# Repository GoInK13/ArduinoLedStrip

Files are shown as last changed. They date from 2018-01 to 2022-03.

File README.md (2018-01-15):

# ArduinoLedStrip
Arduino PCB to control LED strip RGB, addressable or not, with 1 IR remote, 1 pot and 2 push buttons.

**Kicad information**
This project is made using KiCad Version: 4.0.7-e2-6376~58~ubuntu14.04.1.

**Arduino information**
You need the library "RobotIRremote" in your libraries folder. I also modified "TDK2" to "12" in my arduino-1.6.9/libraries/RobotIRremote/src/IRremoteTools.cpp file.

**Component list**
The Arduino used is an ATmega328P Nano V3.
The DC 12V connector is a 5.5mm×2.1mm DC Power Supply Female Jack Socket.
The 6 transistors used are IRFZ44N Transistor N-Channel.
The polarized power capacitor is a 10µF, with a diameter egal to 8.0mm, and a pitch of 3.5mm.
SW1 and SW2 are Push Button DIP P4.
The potentiometer is a PTV09A from Bourns.
The IR receiver is a TSOP4838.
All pin header used have a pitch of 2.54mm.
All resistors are 0603 handsoldering (1kΩ).
Wemos : D1 mini

**Thanks**
Thanks to jerome-labidurie on GitHub for his d1_mini library. (Wemos)
https://github.com/jerome-labidurie/d1_mini_kicad.git

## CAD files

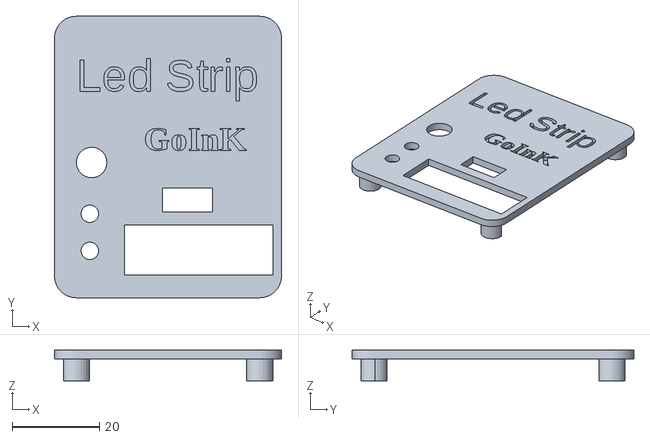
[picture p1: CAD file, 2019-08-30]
FreeCad/top.stl
52.0 x 64.5 x 7.00

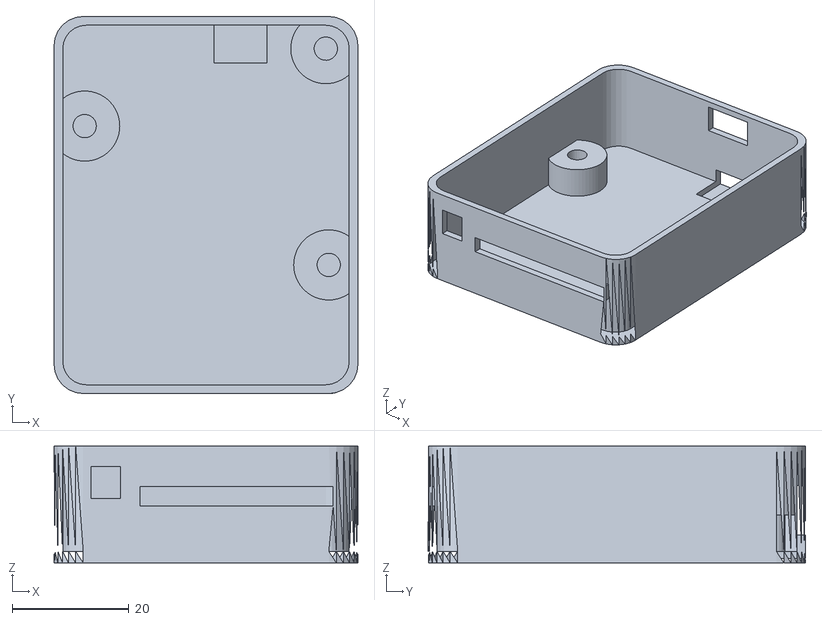
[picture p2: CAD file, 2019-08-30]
FreeCad/bot.stl
52.0 x 64.5 x 20.0

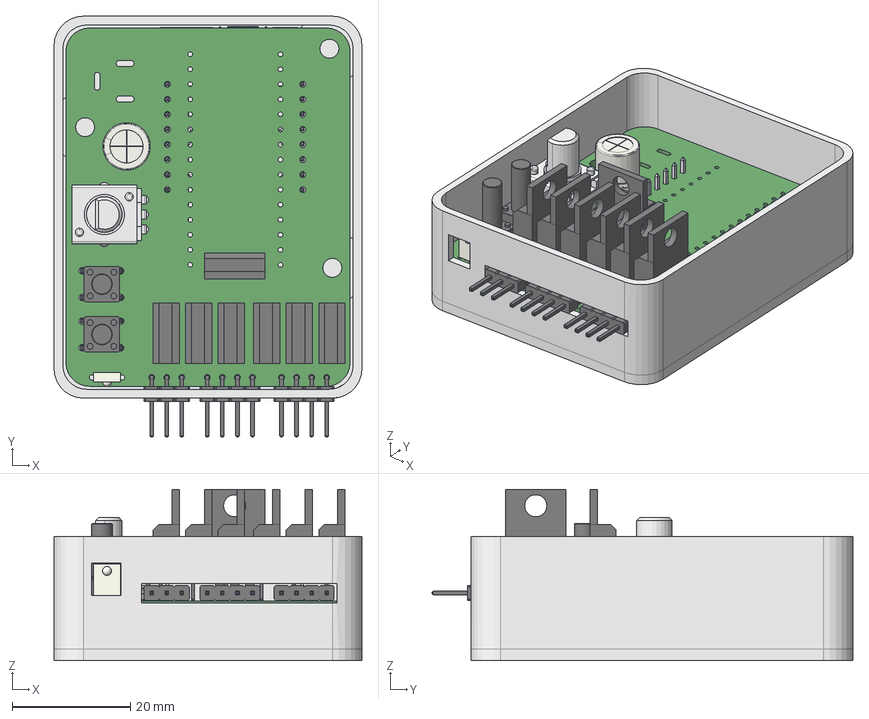
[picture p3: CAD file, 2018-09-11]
FreeCad/ArduinoLedStrip.fcstd
52.0 x 71.0 x 28.9 mm
Bottom2

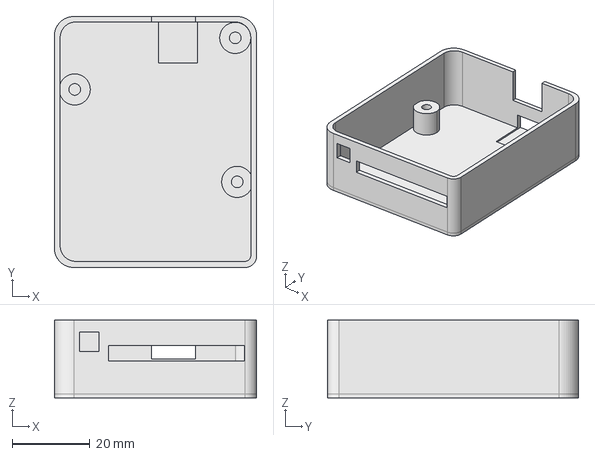
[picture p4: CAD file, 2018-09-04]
FreeCad/Case_Bot.step
52.0 x 64.5 x 20.0 mm

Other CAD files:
FreeCad/Case_top.step

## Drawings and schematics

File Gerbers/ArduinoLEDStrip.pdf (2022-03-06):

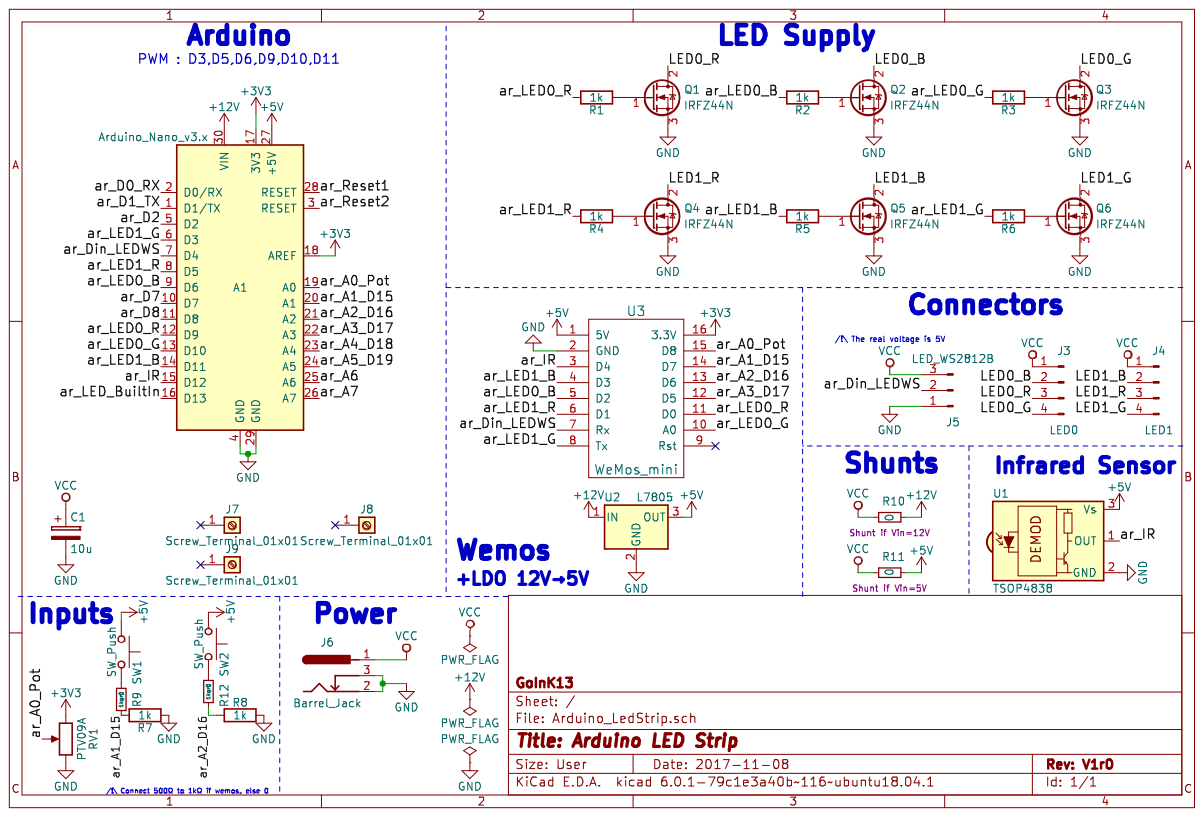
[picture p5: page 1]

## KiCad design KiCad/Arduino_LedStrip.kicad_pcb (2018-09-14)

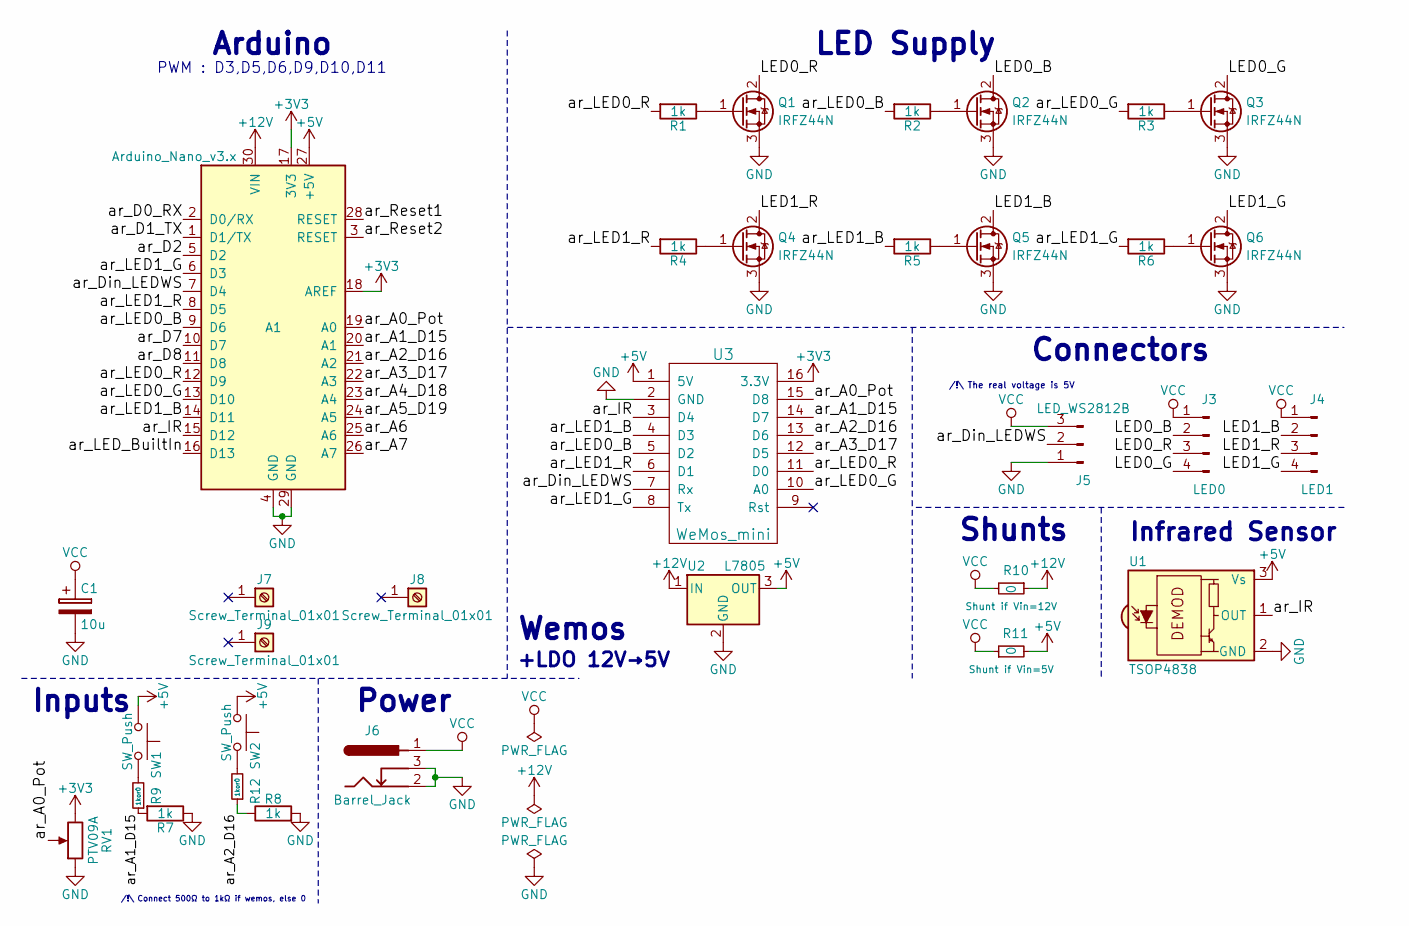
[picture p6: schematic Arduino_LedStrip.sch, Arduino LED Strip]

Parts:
A1: Arduino_Nano_v3.x; Arduino_Nano
C1: 10u; CP_Radial_D8.0mm_P3.50mm
J3: LED0; Pin_Header_Angled_1x04_Pitch2.54mm
J4: LED1; Pin_Header_Angled_1x04_Pitch2.54mm
J5: LED_WS2812B; Pin_Header_Angled_1x03_Pitch2.54mm
J6: Barrel_Jack; BARREL_JACK
J7, J8, J9: Screw_Terminal_01x01; MountingHole_3.2mm_M3
Q1, Q2, Q3, Q4, Q5, Q6: IRFZ44N; TO-220-3_Vertical
R1, R2, R3, R4, R5, R6, R7, R8: 1k; R_0603_HandSoldering
R9, R12: 1kor0; R_0603_HandSoldering
R10, R11: 0; R_Shunt
RV1: PTV09A; Potentiometer_Bourns_PTV09A-1_Horizontal
SW1, SW2: SW_Push; SW_PUSH_6mm_h13mm
U1: TSOP4838; IRReceiver_Vishay_MOLD-3pin
U2: L7805; TO-220-3_Vertical
U3: WeMos_mini; D1_mini_board

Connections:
+3V3: A1.17 (3V3), A1.18 (AREF), RV1.3, U3.16 (3.3V)
+5V: A1.27 (+5V), R11.2, SW1.1, SW2.1, U1.3 (Vs), U2.3 (OUT), U3.1 (5V)
+12V: A1.30 (VIN), R10.1, U2.1 (IN)
/LED0_B: J3.2, Q2.2 (D)
/LED0_G: J3.4, Q3.2 (D)
/LED0_R: J3.3, Q1.2 (D)
/LED1_B: J4.2, Q5.2 (D)
/LED1_G: J4.4, Q6.2 (D)
/LED1_R: J4.3, Q4.2 (D)
/ar_A0_Pot: A1.19 (A0), RV1.2, U3.15 (D8)
/ar_A1_D15: A1.20 (A1), R7.2, R9.1, U3.14 (D7)
/ar_A2_D16: A1.21 (A2), R8.1, R12.1, U3.13 (D6)
/ar_A3_D17: A1.22 (A3), U3.12 (D5)
/ar_A4_D18: A1.23 (A4)
/ar_A5_D19: A1.24 (A5)
/ar_A6: A1.25 (A6)
/ar_A7: A1.26 (A7)
/ar_D0_RX: A1.2 (D0/RX)
/ar_D1_TX: A1.1 (D1/TX)
/ar_D2: A1.5 (D2)
/ar_D7: A1.10 (D7)
/ar_D8: A1.11 (D8)
/ar_Din_LEDWS: A1.7 (D4), J5.2, U3.7 (Rx)
/ar_IR: A1.15 (D12), U1.1 (OUT), U3.3 (D4)
/ar_LED0_B: A1.9 (D6), R2.2, U3.5 (D2)
/ar_LED0_G: A1.13 (D10), R3.2, U3.10 (A0)
/ar_LED0_R: A1.12 (D9), R1.2, U3.11 (D0)
/ar_LED1_B: A1.14 (D11), R5.2, U3.4 (D3)
/ar_LED1_G: A1.6 (D3), R6.2, U3.8 (Tx)
/ar_LED1_R: A1.8 (D5), R4.2, U3.6 (D1)
/ar_LED_BuiltIn: A1.16 (D13)
/ar_Reset1: A1.28 (RESET)
/ar_Reset2: A1.3 (RESET)
GND: A1.4 (GND), A1.29 (GND), C1.2, J5.1, J6.2, J6.3, Q1.3 (S), Q2.3 (S), Q3.3 (S), Q4.3 (S), Q5.3 (S), Q6.3 (S), R7.1, R8.2, RV1.1, U1.2 (GND), U2.2 (GND), U3.2 (GND)
unnamed: Q1.1 (G), R1.1
unnamed: Q2.1 (G), R2.1
unnamed: Q3.1 (G), R3.1
unnamed: Q4.1 (G), R4.1
unnamed: Q5.1 (G), R5.1
unnamed: Q6.1 (G), R6.1
unnamed: R9.2, SW1.2
unnamed: R12.2, SW2.2
VCC: C1.1, J3.1, J4.1, J5.3, J6.1, R10.2, R11.1

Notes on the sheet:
PWM : D3,D5,D6,D9,D10,D11
Power
Inputs
Arduino
LED Supply
Connectors
Infrared Sensor
/!\ The real voltage is 5V
Wemos
+LDO 12V→5V
Shunts
/!\ Connect 500Ω to 1kΩ if wemos, else 0

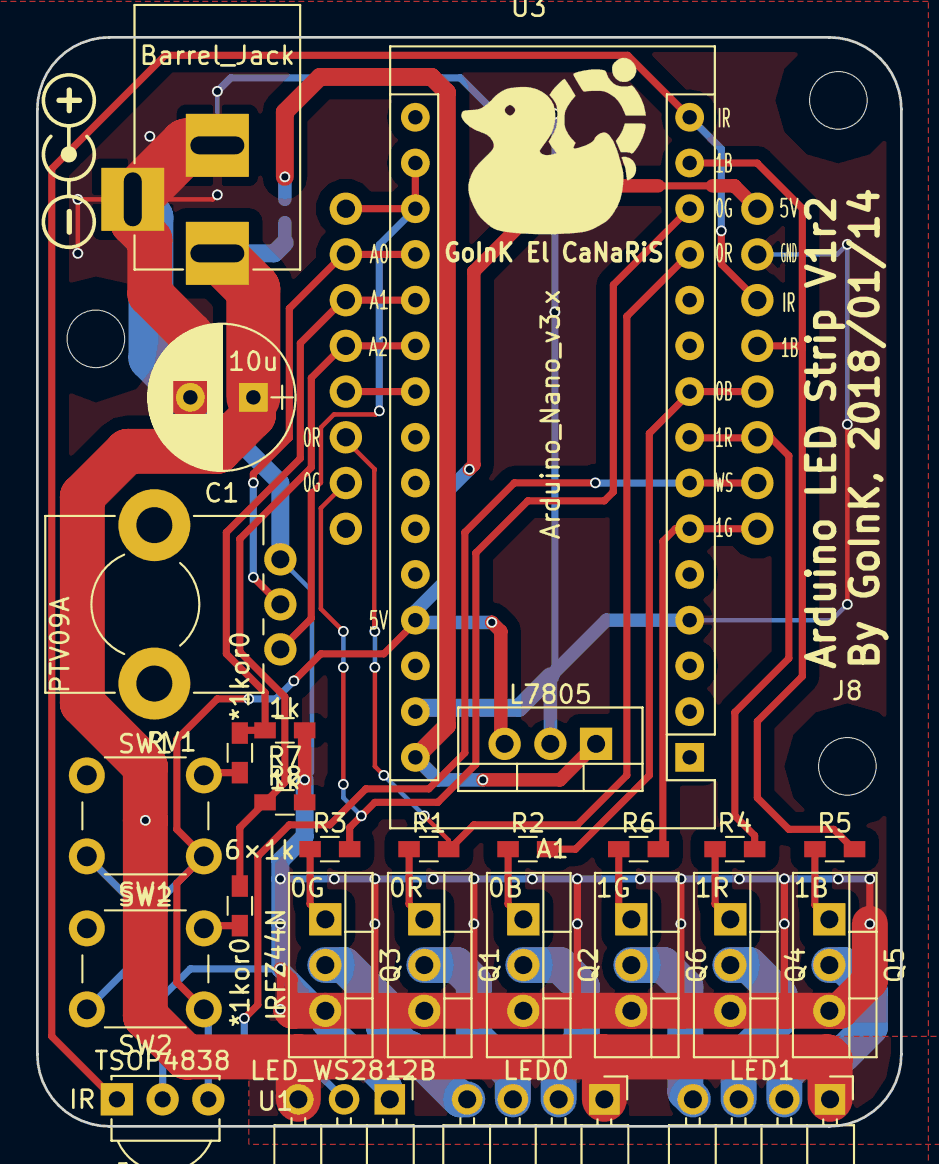
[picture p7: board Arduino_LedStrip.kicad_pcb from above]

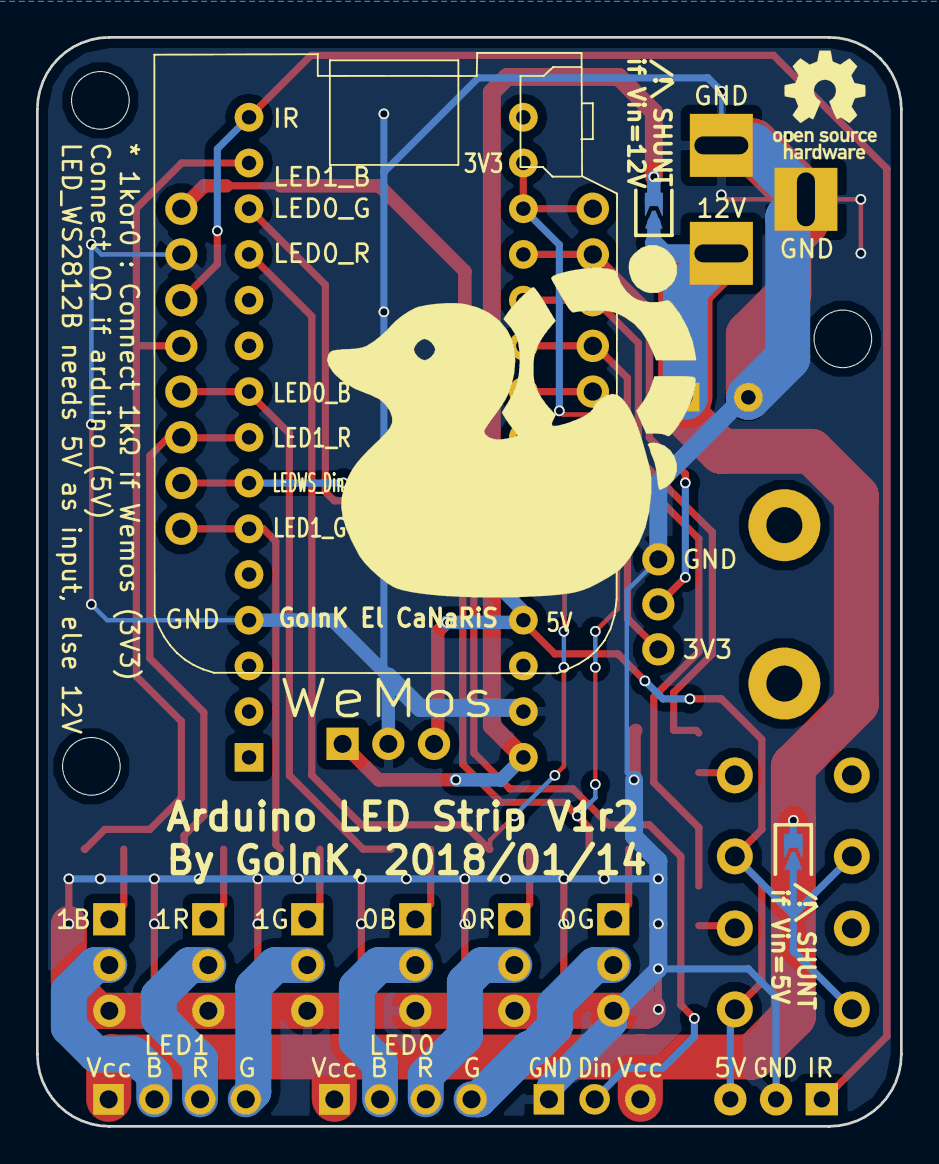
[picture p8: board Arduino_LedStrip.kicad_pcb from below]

Board: 2 copper layers, 48.0 x 60.5 mm, 33 parts (2 on the bottom side), 31 nets.

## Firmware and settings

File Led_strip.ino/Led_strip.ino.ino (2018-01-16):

/*
   20DF9E61 = Ratio
   20DF8976 = AD
*/

#include <IRremote.h>
#include "define.h"
#include <EEPROM.h>

//Uncomment the next to enable USB debug
//#define DBG
//Next is removed, bevause LED1_R doesn't work with IR_Receiver…
//#define IR_RECV

//Const
//const int pwmStepSize = 50;		//Choose number of step for PWM brightness.
//int pwmStep[pwmStepSize]; //Old value : = {0,1,2,5,8,11,15,20,26,33,41,51,64,80,100,125,160,200,255};
const int pwmStepSize = 37;    //Number of step for PWM brightness.
int pwmStep[] = {0, 1, 2, 3, 4, 5, 6, 7, 8, 9, 11, 13, 15, 17, 19, 22, 25, 28, 32, 36, 40, 45, 51, 57, 64, 72, 81, 91, 102, 114, 128, 143, 161, 180, 202, 226, 255};

//Current settings
int pwmIndexR = 0, pwmIndexG = 0, pwmIndexB = 0;		//Current PWM settings
int cntTransition = 0;	//Count transition for fade and jump.
int stateSet = 0;	//Number of settings currently setting. 0 : settings currently not enabled
int mode = 0; //0:color fixed. 1:RGB fading. 2:RGB jumping. 3:Night = Slowly turn OFF, then ON after Xhours

//Saved in EEPROM. To update eeprom after values have changed, you need to click the setting button until going to set 0.
int set0_R, set0_G, set0_B;	//Mode 0 : fix color
int set1_speed;	//Speed transition in ms. Fade
int set2_speed;	//Speed transition in ms. Jump
//Color before night and after. delayNight is in 30min + 5h. ie:2blinks=6h
int set3_colorBeforeR, set3_colorBeforeG, set3_colorBeforeB, set3_colorAfterR, set3_colorAfterG, set3_colorAfterB, set3_delayNight;

unsigned long mode3_nightStarting;	//millis() start when entering in this mode

unsigned int oldPot=0;	//Save the old value of POT, before update it

//Next two lines are used for IR receiver. I added a "2" because I had some compilation troubble with the lib IRremote.h.
//I also changed "TKD2" in IRremoteTools.cpp with "12"

#ifdef IR_RECV
IRrecv irrecv2(IR_RECV_PIN);
decode_results results2;
#endif

void setup()
{
  //Define all output
  //Internal LED used to see good IR reception
  pinMode(LED_BUILTIN, OUTPUT);
  pinMode(LED0_R, OUTPUT);
  pinMode(LED0_G, OUTPUT);
  pinMode(LED0_B, OUTPUT);
  pinMode(LED1_R, OUTPUT);
  pinMode(LED1_G, OUTPUT);
  pinMode(LED1_B, OUTPUT);
  pinMode(LEDWS_Din, OUTPUT);
  //Set all LED to LOW
  digitalWrite(LED_BUILTIN, HIGH);
  digitalWrite(LED0_R, LOW);
  digitalWrite(LED0_G, LOW);
  digitalWrite(LED0_B, LOW);
  digitalWrite(LED1_R, LOW);
  digitalWrite(LED1_G, LOW);
  digitalWrite(LED1_B, LOW);
  digitalWrite(LEDWS_Din, LOW);
  //Inputs : Push button and analog
  pinMode(BUTTON0, INPUT);
  pinMode(BUTTON1, INPUT);
  //Pot doesn't need to be initialized, because it's an analog
  //Save number of values in pwmStep

  //Init values from EEPROM
  if (EEPROM.read(101) != 1 || (digitalRead(BUT_MODE) == 1 && digitalRead(BUT_SET) == 1)) {	//Two buttons pressed on boot = RESET settings
    mode = 0;
    set0_R = pwmStepSize - 1;
    set0_G = pwmStepSize - 1;
    set0_B = pwmStepSize - 1;
    set1_speed = 100;
    set2_speed = 100;
    set3_colorBeforeR = pwmStepSize - 1;
    set3_colorBeforeG = pwmStepSize - 1;
    set3_colorBeforeB = pwmStepSize - 1;
    set3_colorAfterR = pwmStepSize - 1;
    set3_colorAfterG = pwmStepSize - 1;
    set3_colorAfterB = pwmStepSize - 1;
    set3_delayNight = 4;
    EepromUpdateAll();	//Save all
  } else {
    mode = EEPROM.read(100);
    //Mode 0
    set0_R = EEPROM.read(1);
    set0_G = EEPROM.read(2);
    set0_B = EEPROM.read(3);
    //Mode 1
    set1_speed = EEPROM.read(10);
    //Mode 2
    set2_speed = EEPROM.read(20);
    //Mode 3
    set3_colorBeforeR = EEPROM.read(30);
    set3_colorBeforeG = EEPROM.read(31);
    set3_colorBeforeB = EEPROM.read(32);
    set3_colorAfterR = EEPROM.read(33);
    set3_colorAfterG = EEPROM.read(34);
    set3_colorAfterB = EEPROM.read(35);
    set3_delayNight = EEPROM.read(36);
  }
  /*
    //Update pwmStep using pwm exponential led fading method. Thanks to diarmuidie : https://diarmuid.ie/blog/pwm-exponential-led-fading-on-arduino-or-other-platforms/
    float R = ((pwmStepSize-1) * log10(2))/(log10(255));
    for (int interval = 0; interval < pwmStepSize; interval++) {
  	// Calculate the required PWM value for this interval step
  	pwmStep[interval]=pow(2, (interval / R)) - 1;
    }
  */

#ifdef IR_RECV
  irrecv2.enableIRIn(); // Start the receiver
#endif
#ifdef DBG
  Serial.begin(115200);
  Serial.print("Enabled IRin.! pwmStep=");
  Serial.println(pwmStepSize);
#endif
  delay(100);		//Slow booting delay to see the BUILTIN LED blink
  digitalWrite(LED_BUILTIN, LOW);
}

void loop() {

#ifdef IR_RECV
  if (irrecv2.decode(&results2)) {	//IR decoded
    digitalWrite(LED_BUILTIN, HIGH);
#ifdef DBG
    Serial.print(pwmIndexR);
    Serial.print(". VAL=");
    Serial.print(results2.value, HEX);
#endif
    if (results2.value == IR_LG_BLUE) {	//Increase power of blue
      if (pwmIndexB < pwmStepSize - 1)
        pwmIndexB++;
    } else if (results2.value == IR_LG_RED) {
      if (pwmIndexR < pwmStepSize - 1)
        pwmIndexR++;
    } else if (results2.value == IR_LG_GREEN) {
      if (pwmIndexG < pwmStepSize - 1)
        pwmIndexG++;
    }
    analogWrite(LED0_R, pwmStep[pwmIndexR]);
    analogWrite(LED0_G, pwmStep[pwmIndexG]);
    analogWrite(LED0_B, pwmStep[pwmIndexB]);
    analogWrite(LED1_R, pwmStep[pwmIndexR]);
    analogWrite(LED1_G, pwmStep[pwmIndexG]);
    analogWrite(LED1_B, pwmStep[pwmIndexB]);
    irrecv2.resume(); // Receive the next value
  }
#endif
  if (digitalRead(BUT_MODE) == 1) {	//Transition button mode
    while (digitalRead(BUT_MODE) == 1);  //Wait releasing button
    Blink(mode + 1);
    stateSet = 0;
    pwmIndexR = 0;
    pwmIndexG = 0;
    pwmIndexB = 0;
    cntTransition = 0;
    if (mode == 3) {	//Mode night
      mode3_nightStarting = millis();
    }
    if (mode == 0) {
      EepromUpdateAll();  //Save all
    }
  }
  if (digitalRead(BUT_SET) == 1) {	//Transition button mode
    ShowSettings(stateSet + 1);
    oldPot=analogRead(POT);
    while (digitalRead(BUT_SET) == 1);	//Wait releasing button
  }
  if (stateSet != 0) {
    SetSettings();
  } else {
    UpdateLED(mode);
  }
  LightLED();

#ifdef DBG
  Serial.println();
  Serial.print("Mode=");
  Serial.print(mode);
  Serial.print(", set=");
  Serial.print(stateSet);
  Serial.print(",R=");
  Serial.print(pwmIndexR);
  Serial.print(",G=");
  Serial.print(pwmIndexG);
  Serial.print(",B=");
  Serial.print(pwmIndexB);
  Serial.print(",POT=");
  Serial.print(analogRead(POT));
  delay(100);
#endif
}

//-----------FUNCTIONS-----------

/*
	UpdateLED from mode
*/
void UpdateLED(int _mode) {
  if (_mode == 0) {		//Fix
    pwmIndexR = set0_R;
    pwmIndexG = set0_G;
    pwmIndexB = set0_B;
  } else if (_mode == 1) {
    cntTransition = cntTransition >= 6 * pwmStepSize ? 0 : cntTransition + 1;
    /*
      0    0    0    OFF        ---
      0    0    1    Blue       470
      0    1    1    Turquoise  510     Représentant les couleurs selon leur longueur
      0    1    0    Green      540     d'onde, de la plus faible à la plus grande
      1    1    0    Yellow     575
      1    0    0    Red        650
      1    0    1    Pink       400
      1    1    1    White      ---
    */
    if (cntTransition <= 1 * pwmStepSize) {
      pwmIndexR = pwmIndexR == 0 ? 0 : pwmIndexR - 1;
    } else if (cntTransition <= 2 * pwmStepSize) {
      pwmIndexG = pwmIndexG >= pwmStepSize - 1 ? pwmStepSize - 1 : pwmIndexG + 1;
    } else if (cntTransition <= 3 * pwmStepSize) {
      pwmIndexB = pwmIndexB == 0 ? 0 : pwmIndexB - 1;
    } else if (cntTransition <= 4 * pwmStepSize) {
      pwmIndexR = pwmIndexR >= pwmStepSize - 1 ? pwmStepSize - 1 : pwmIndexR + 1;
    } else if (cntTransition <= 5 * pwmStepSize) {
      pwmIndexG = pwmIndexG == 0 ? 0 : pwmIndexG - 1;
    } else if (cntTransition <= 6 * pwmStepSize) {
      pwmIndexB = pwmIndexB >= pwmStepSize - 1 ? pwmStepSize - 1 : pwmIndexB + 1;
    }
    DelayInter(set1_speed);
  } else if (_mode == 2) { //Jump
    cntTransition = cntTransition >= 6 ? 1 : cntTransition + 1;
    /*
      R    G    B
      0    0    1    Blue       470		001	1
      0    1    1    Turquoise  510     010	2
      0    1    0    Green      540     011	3
      1    1    0    Yellow     575		100	4
      1    0    0    Red        650		101	5
      1    0    1    Pink       400		110	6
    */
    if (cntTransition == 1 || cntTransition == 2 || cntTransition == 6) {
      pwmIndexB = pwmStepSize-1;
    } else {
      pwmIndexB = 0;
    }
    if (cntTransition == 2 || cntTransition == 3 || cntTransition == 4) {
      pwmIndexG = pwmStepSize-1;
    } else {
      pwmIndexG = 0;
    }
    if (cntTransition == 4 || cntTransition == 5 || cntTransition == 6) {
      pwmIndexR = pwmStepSize-1;
    } else {
      pwmIndexR = 0;
    }
    DelayInter(set2_speed);
  } else if (_mode == 3) {	//Night
    if (millis() - mode3_nightStarting < 1800000) { //30 first minutes
      static unsigned long temp_powerNight;
      temp_powerNight = (millis() - mode3_nightStarting) * pwmStepSize / 1800000;
      pwmIndexR = set3_colorBeforeR * (pwmStepSize - temp_powerNight) / pwmStepSize;
      pwmIndexG = set3_colorBeforeG * (pwmStepSize - temp_powerNight) / pwmStepSize;
      pwmIndexB = set3_colorBeforeB * (pwmStepSize - temp_powerNight) / pwmStepSize;
    } else if (millis() - mode3_nightStarting < 21600000 + set3_delayNight * 1800000) { //During night
      pwmIndexR = 0;
      pwmIndexG = 0;
      pwmIndexB = 0;
    } else {
      static unsigned long temp_powerNight;
      temp_powerNight = (millis() - mode3_nightStarting - 0 - set3_delayNight * 30000) * pwmStepSize / 30000;
      temp_powerNight = (millis() - mode3_nightStarting - 21600000 - set3_delayNight * 1800000) * pwmStepSize / 1800000;
      if (temp_powerNight < pwmStepSize) {
        pwmIndexR = set3_colorAfterR * temp_powerNight / pwmStepSize;
        pwmIndexG = set3_colorAfterG * temp_powerNight / pwmStepSize;
        pwmIndexB = set3_colorAfterB * temp_powerNight / pwmStepSize;
      } else {
        pwmIndexR = set3_colorAfterR;
        pwmIndexG = set3_colorAfterG;
        pwmIndexB = set3_colorAfterB;
      }
    }
  }
}

/*
	Light LED using global pwm_index
*/
void LightLED() {
  analogWrite(LED0_R, pwmStep[pwmIndexR]);
  analogWrite(LED0_G, pwmStep[pwmIndexG]);
  analogWrite(LED0_B, pwmStep[pwmIndexB]);
  analogWrite(LED1_R, pwmStep[pwmIndexR]);
  analogWrite(LED1_G, pwmStep[pwmIndexG]);
  analogWrite(LED1_B, pwmStep[pwmIndexB]);
}
/*
	Update variables settings in current mode and settings. Use Analog
*/
void SetSettings() {
  int i;
  static unsigned int localR=0, localG=0, localB=0;
  static unsigned int localTemp = 0;
  if (mode == 0) {
    if (stateSet == 1) {		//All
      if (oldPot/5!=analogRead(POT)/5) {    // /5 : avoid low oscillations
        oldPot=-1;  //Set impossible value to oldPot. Avoid oldPot==analogRead(POT)
        TurnAllLED_Pot(analogRead(POT), &pwmIndexR, &pwmIndexG, &pwmIndexB);
      } else {
        pwmIndexR=set0_R;
        pwmIndexG=set0_G;
        pwmIndexB=set0_B;
      }
      localR=pwmIndexR;
      localG=pwmIndexG;
      localB=pwmIndexB;
    } else if (stateSet == 2) {
      if (oldPot/5!=analogRead(POT)/5) {    // /5 : avoid low oscillations
        oldPot=-1;  //Set impossible value to oldPot. Avoid oldPot==analogRead(POT)
        pwmIndexR = (unsigned long) localR*analogRead(POT)/1023;
        pwmIndexG = (unsigned long) localG*analogRead(POT)/1023;
        pwmIndexB = (unsigned long) localB*analogRead(POT)/1023;
      } else {
        pwmIndexR=localR;
        pwmIndexG=localG;
        pwmIndexB=localB;
      }
    }
  } else if (mode == 1) {
    if (stateSet == 1 || stateSet == 2) {
      cntTransition = cntTransition >= 6 * pwmStepSize ? 0 : cntTransition + 1;
      if (cntTransition <= 1 * pwmStepSize) {
        localR = localR == 0 ? 0 : localR - 1;
      } else if (cntTransition <= 2 * pwmStepSize) {
        localG = localG >= pwmStepSize-1 ? pwmStepSize-1 : localG + 1;
      } else if (cntTransition <= 3 * pwmStepSize) {
        localB = localB == 0 ? 0 : localB - 1;
      } else if (cntTransition <= 4 * pwmStepSize) {
        localR = localR >= pwmStepSize-1 ? pwmStepSize-1 : localR + 1;
      } else if (cntTransition <= 5 * pwmStepSize) {
        localG = localG == 0 ? 0 : localG - 1;
      } else if (cntTransition <= 6 * pwmStepSize) {
        localB = localB >= pwmStepSize-1 ? pwmStepSize-1 : localB + 1;
      }
      if (stateSet==1) {
        localTemp=analogRead(POT) < 4 ? 1 : analogRead(POT) / 4;
        DelayInter(localTemp);
        pwmIndexR=localR;
        pwmIndexG=localG;
        pwmIndexB=localB;
      } else if (stateSet==2) {
        DelayInter(localTemp);
        pwmIndexR = (unsigned long) localR*analogRead(POT)/1023;
        pwmIndexG = (unsigned long) localG*analogRead(POT)/1023;
        pwmIndexB = (unsigned long) localB*analogRead(POT)/1023;
      }
    }
  } else if (mode == 2) {
    if (stateSet == 1 || stateSet == 2) {
      cntTransition = cntTransition >= 6 ? 1 : cntTransition + 1;
      if (cntTransition == 1 || cntTransition == 2 || cntTransition == 6) {
        localB = pwmStepSize-1;
      } else {
        localB = 0;
      }
      if (cntTransition == 2 || cntTransition == 3 || cntTransition == 4) {
        localG = pwmStepSize-1;
      } else {
        localG = 0;
      }
      if (cntTransition == 4 || cntTransition == 5 || cntTransition == 6) {
        localR = pwmStepSize-1;
      } else {
        localR = 0;
      }
      
      if (stateSet==1) {
        localTemp=analogRead(POT) * 3;
        DelayInter(localTemp);
        pwmIndexR=localR;
        pwmIndexG=localG;
        pwmIndexB=localB;
      } else if (stateSet==2) {
        DelayInter(localTemp);
        pwmIndexR = (unsigned long) localR*analogRead(POT)/1023;
        pwmIndexG = (unsigned long) localG*analogRead(POT)/1023;
        pwmIndexB = (unsigned long) localB*analogRead(POT)/1023;
      }
    }
  } else if (mode == 3) {
    if (stateSet == 1) {	//		set3_colorBefore
      if (oldPot/5!=analogRead(POT)/5) {    // /5 : avoid low oscillations
        oldPot=-1;  //Set impossible value to oldPot. Avoid oldPot==analogRead(POT)
        TurnAllLED_Pot(analogRead(POT), &pwmIndexR, &pwmIndexG, &pwmIndexB);
      } else {
        pwmIndexR=set3_colorBeforeR;
        pwmIndexG=set3_colorBeforeG;
        pwmIndexB=set3_colorBeforeB;
      }
    } else if (stateSet == 2) {		//set3_colorAfter
      if (oldPot/5!=analogRead(POT)/5) {
        oldPot=-1;  //Set impossible value to oldPot. Avoid oldPot==analogRead(POT)
        TurnAllLED_Pot(analogRead(POT), &pwmIndexR, &pwmIndexG, &pwmIndexB);
      } else {
        pwmIndexR=set3_colorAfterR;
        pwmIndexG=set3_colorAfterG;
        pwmIndexB=set3_colorAfterB;
      }
    } else if (stateSet == 3) {		//set3_delayNight;
      static int temp_delayNight = 0;
      pwmIndexR=0;
      pwmIndexG=0;
      pwmIndexB=0;
      if (oldPot/5==analogRead(POT)/5) {
        temp_delayNight=set3_delayNight;
      } else if (temp_delayNight != analogRead(POT) / 80) {
        oldPot=-1;  //Set impossible value to oldPot. Avoid oldPot==analogRead(POT)
        temp_delayNight = analogRead(POT) / 80;
//        DelayInter(100);
        TurnLED(TURN_RED);
        DelayInter(200);
        TurnLED(TURN_OFF);
        DelayInter(400);
      }
      TurnLED(TURN_OFF);
      delay(100);
      for (int i = 0; i < temp_delayNight; i += 1) {
        TurnLED(TURN_WHITE);
        DelayInter(250);
        if (temp_delayNight != analogRead(POT) / 80 || digitalRead(BUT_SET) == 1) return;
        TurnLED(TURN_OFF);
        DelayInter(250);
        if (temp_delayNight != analogRead(POT) / 80 || digitalRead(BUT_SET) == 1) return;
      }
      for (int i = 0; i < 20; i += 1) {
        if (temp_delayNight == analogRead(POT) / 80 && digitalRead(BUT_SET) == 0 && digitalRead(BUT_MODE) == 0) DelayInter(50);
        else return;
      }
    }
  }
}

/*
	ShowSettings shows the current settings that you can set using the analog
*/
void ShowSettings(int _settings) {
  int i;
  if (mode == 0) {
    stateSet = (_settings <= 2) ? _settings : 0;
    if (stateSet == 0) {    //Save when return settings to 0
      set0_R = pwmIndexR;
      set0_G = pwmIndexG;
      set0_B = pwmIndexB;
    }
    if (stateSet == 1) {    //All
      TurnLED(TURN_OFF);
      delay(150);
      TurnLED(TURN_RED);
      delay(300);
      TurnLED(TURN_GREEN);
      delay(300);
      TurnLED(TURN_BLUE);
      delay(300);
      TurnLED(TURN_OFF);
      delay(300);
    } else if (stateSet == 2) {   //Change brightness
      TurnLED(TURN_WHITE);
      delay(150);
      for (i = pwmStepSize-1; i >= 0; i -= 1) {
        analogWrite(LED0_R, pwmStep[i]);
        analogWrite(LED0_G, pwmStep[i]);
        analogWrite(LED0_B, pwmStep[i]);
        analogWrite(LED1_R, pwmStep[i]);
        analogWrite(LED1_G, pwmStep[i]);
        analogWrite(LED1_B, pwmStep[i]);
        delay(500 / pwmStepSize);
      }
    }
  } else if (mode == 1) {
    stateSet = (_settings <= 2) ? _settings : 0;
    if (stateSet == 0) {
      set1_speed = analogRead(POT) < 4 ? 1 : analogRead(POT) / 4;
    }
    if (stateSet == 1) {
      TurnLED(TURN_OFF);
      delay(150);
      for (i = 0; i < pwmStepSize; i += 1) {
        analogWrite(LED0_R, pwmStep[i]);
        analogWrite(LED0_G, pwmStep[i]);
        analogWrite(LED0_B, pwmStep[i]);
        analogWrite(LED1_R, pwmStep[i]);
        analogWrite(LED1_G, pwmStep[i]);
        analogWrite(LED1_B, pwmStep[i]);
        delay(500 / pwmStepSize);
      }
      for (i = pwmStepSize - 1; i >= 0; i -= 1) {
        analogWrite(LED0_R, pwmStep[i]);
        analogWrite(LED0_G, pwmStep[i]);
        analogWrite(LED0_B, pwmStep[i]);
        analogWrite(LED1_R, pwmStep[i]);
        analogWrite(LED1_G, pwmStep[i]);
        analogWrite(LED1_B, pwmStep[i]);
        delay(500 / pwmStepSize);
      }
      delay(300);
    } else if (stateSet == 2) {   //Change brightness
      TurnLED(TURN_BLUE);
      delay(150);
      for (i = pwmStepSize-1; i >= 0; i -= 1) {
        analogWrite(LED0_B, pwmStep[i]);
        analogWrite(LED1_B, pwmStep[i]);
        delay(500 / pwmStepSize);
      }
    }
  } else if (mode == 2) {
    stateSet = (_settings <= 2) ? _settings : 0;
    if (stateSet == 0) {
      set2_speed = analogRead(POT) * 3;
    } else if (stateSet == 1) {
      TurnLED(TURN_OFF);
      delay(100);
      for (i = 0; i < 7; i += 1) {
        TurnLED(i);
        delay(50);
        TurnLED(TURN_OFF);
        delay(50);
      }
      delay(300);
    } else if (stateSet == 2) {   //Change brightness
      TurnLED(TURN_GREEN);
      delay(150);
      for (i = pwmStepSize-1; i >= 0; i -= 1) {
        analogWrite(LED0_G, pwmStep[i]);
        analogWrite(LED1_G, pwmStep[i]);
        delay(500 / pwmStepSize);
      }
    }
  } else if (mode == 3) {
    stateSet = (_settings <= 3) ? _settings : 0;
    if (stateSet == 0) {
      //Save set3_delayNight if it has changed
      if (oldPot != analogRead(POT)) {
        set3_delayNight = analogRead(POT) / 80;
      }
      mode3_nightStarting = millis();
    } else if (stateSet == 1) {	//		set3_colorBefore
      TurnLED(TURN_YELLOW);
      delay(150);
      for (i = pwmStepSize; i >= 0 ; i -= 1) {
        analogWrite(LED0_R, pwmStep[i]);
        analogWrite(LED0_G, pwmStep[i]);
        analogWrite(LED1_R, pwmStep[i]);
        analogWrite(LED1_G, pwmStep[i]);
        delay(500 / pwmStepSize);
      }
      TurnLED(TURN_OFF);
      delay(300);
    } else if (stateSet == 2) {		//set3_colorAfter
      //Save set3_colorBefore if it has changed
      if (oldPot != analogRead(POT)) {
        set3_colorBeforeR = pwmIndexR;
        set3_colorBeforeG = pwmIndexG;
        set3_colorBeforeB = pwmIndexB;
      }
      TurnLED(TURN_OFF);
      delay(150);
      for (i = 0; i < pwmStepSize; i += 1) {
        analogWrite(LED0_B, pwmStep[i]);
        analogWrite(LED0_G, pwmStep[i]);
        analogWrite(LED1_B, pwmStep[i]);
        analogWrite(LED1_G, pwmStep[i]);
        delay(500 / pwmStepSize);
      }
      TurnLED(TURN_OFF);
      delay(300);
    } else if (stateSet == 3) {		//set3_delayNight;
      if (oldPot != analogRead(POT)) {
        set3_colorAfterR = pwmIndexR;
        set3_colorAfterG = pwmIndexG;
        set3_colorAfterB = pwmIndexB;
      }
      TurnLED(TURN_YELLOW);
      delay(150);
      for (i = pwmStepSize; i >= 0 ; i -= 1) {
        analogWrite(LED0_R, pwmStep[i]);
        analogWrite(LED0_G, pwmStep[i]);
        analogWrite(LED1_R, pwmStep[i]);
        analogWrite(LED1_G, pwmStep[i]);
        delay(250 / pwmStepSize);
      }
      TurnLED(TURN_OFF);
      delay(50);
      TurnLED(TURN_WHITE);
      delay(50);
      TurnLED(TURN_OFF);
      delay(50);
      TurnLED(TURN_WHITE);
      delay(50);
      TurnLED(TURN_OFF);
      delay(150);
      for (i = 0; i < pwmStepSize; i += 1) {
        analogWrite(LED0_B, pwmStep[i]);
        analogWrite(LED0_G, pwmStep[i]);
        analogWrite(LED1_B, pwmStep[i]);
        analogWrite(LED1_G, pwmStep[i]);
        delay(500 / pwmStepSize);
      }
      delay(150);
    }
  }
  if (stateSet == 0) {		//Anim leaving settings
    for (i = pwmStepSize - 1; i >= 0; i -= 1) {
      analogWrite(LED0_R, pwmStep[i]);
      analogWrite(LED0_G, pwmStep[i]);
      analogWrite(LED0_B, pwmStep[i]);
      analogWrite(LED1_R, pwmStep[i]);
      analogWrite(LED1_G, pwmStep[i]);
      analogWrite(LED1_B, pwmStep[i]);
      delay(500 / pwmStepSize);
    }
  }
}

/*
	Blink LED to know the mode
*/
void Blink(int _mode) {
  mode = (_mode < 4) ? _mode : 0;
  int i;
  TurnLED(TURN_OFF);
  DelayInter(200);
  for (i = 0; i < mode + 1; i += 1) {
    TurnLED(TURN_WHITE);
    DelayInter(400);
    TurnLED(TURN_OFF);
    DelayInter(400);
  }
  DelayInter(400);
}
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

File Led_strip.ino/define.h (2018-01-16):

#define IR_LG_RATIO	0x20DF9E61
#define IR_LG_AD		 0x20DF8976
#define IR_LG_TEXT	 0x20DF04FB
#define IR_LG_TOPT	 0x20DF847B
#define IR_LG_SUBTITLE 0x20DF9C63
#define IR_LG_STOP	 0x20DF8D72
#define IR_LG_PLAY	 0x20DF0DF2
#define IR_LG_PAUSE	0x20DF5DA2
#define IR_LG_PREV	 0x20DFF10E
#define IR_LG_NEXT	 0x20DF718E
#define IR_LG_SIMPLX 0x20DF7E81
#define IR_LG_RED		0x20DF4EB1
#define IR_LG_GREEN	0x20DF8E71
#define IR_LG_BLUE	 0x20DF8679
#define IR_LG_YELL	 0x20DFC639
//IR Receiver
#define IR_RECV_PIN 12
//LEDs
#define LEDWS_Din 4
#define LED0_R    10
#define LED0_G    11
#define LED0_B    9
#define LED1_R    3
#define LED1_G    6
#define LED1_B    5
//#define LED_BUILTIN 13  //Good reception IR
//Buttons
#define POT   A0   //Analog
#define BUTTON0   15		//Used to change mode
#define BUTTON1   16		//Used to set mode

#define BUT_MODE BUTTON0
#define BUT_SET BUTTON1

#define TURN_OFF	0
#define TURN_RED	1
#define TURN_GREEN	2
#define TURN_YELLOW	3
#define TURN_BLUE	4
#define TURN_PINK	5
#define TURN_TURQ	6
#define TURN_WHITE	7

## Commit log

2017-11-16 End of schematic. First placement.
    [Arduino_LedStrip.kicad_pcb, Arduino_LedStrip.sch]
2017-11-23 Routing PCB
    [Arduino_LedStrip.kicad_pcb, Arduino_LedStrip.sch]
2017-11-24 Update routing.
    [Arduino_LedStrip.kicad_pcb]
2017-11-24 Rotate SW1 and SW2.
    [Arduino_LedStrip.kicad_pcb]
2017-11-29 Finish routing. Rearrange folders. Add Arduino folder with sketch.
    [Arduino_LedStrip-B.Cu.gbl, Arduino_LedStrip-B.Mask.gbs, Arduino_LedStrip-B.SilkS.gbo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]
2017-12-10 Draft Arduino INO.
2017-12-10 Change folder Arduino
2017-12-17 Update schematic. Change NMOS_GSD to GDS (TO220). Change 5V IR
    [Arduino_LedStrip-B.Cu.gbl, Arduino_LedStrip-B.Mask.gbs, Arduino_LedStrip-B.SilkS.gbo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]
2017-12-17 Update names. Add the 3 others LED
2017-12-31 Remove IR_RECEIVER which block D3 (LED1_R)
2018-01-08 Correct some bugs. Work on mode 4 blinks.
    [Led_strip.ino.ino]
2018-01-14 Change mode when simple click during animation. Show old value in mode 4 when in settings.
    [Arduino_LedStrip.kicad_pcb, Arduino_LedStrip.sch]
2018-01-14 Add possibility to use a 5V or 12V power. Create new gerbers
    [Arduino_LedStrip-B.Cu.gbl, Arduino_LedStrip-B.Mask.gbs, Arduino_LedStrip-B.SilkS.gbo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]
2018-01-14 Update silks bot
    [Arduino_LedStrip.kicad_pcb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]
2018-01-15 Update folder paths. Add Wemos.
    [Arduino_LedStrip-B.Cu.gbl, Arduino_LedStrip-B.Mask.gbs, Arduino_LedStrip-B.SilkS.gbo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]
2018-05-10 Change silks : 5V bot to 3V3.
    [Arduino_LedStrip.kicad_pcb]
2018-09-03 Add 3D compatible KiCad5
    [Arduino_LedStrip.kicad_pcb]
2018-09-04 Add freecad box.
    [ArduinoLedStrip.fcstd, Case_Bot.step, Case_top.step]
2018-09-11 Need hole for bottom.
    [ArduinoLedStrip.fcstd]
2018-09-11 Hole from LED done.
    [ArduinoLedStrip.fcstd]
2018-09-14 Up 3D : Add Arduino Nano.
    [Arduino_LedStrip.kicad_pcb]
2019-08-30 Add stl file
    [bot.stl, top.stl]
